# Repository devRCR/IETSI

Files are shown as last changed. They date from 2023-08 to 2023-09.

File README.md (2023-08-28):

# Sistema de llamada para pacientes mediante módulos inalámbricos

Solución tecnológica diseñada para facilitar la comunicación entre el personal médico o de enfermería y los pacientes en entornos de atención médica, como hospitales o clínicas, mediante el uso de módulos de radiofrecuencia con pulsadores que realizan las funciones de "Atender paciente", "Rellamar" y "Finalizar".

## Table of Contents

- [Introducción](#introducción)
- [Características](#características)
- [Requisitos](#requisitos)
- [Instalación](#instalación)
- [Uso](#uso)
- [Contribución](#contribución)
- [Licencia](#licencia)
- [Contacto](#contacto)

## Introducción

Proporciona una introducción concisa de lo que hace tu proyecto y por qué es relevante. Incluye un resumen de las principales características y beneficios.

## Características

Enumera las características clave de tu proyecto. Esto puede ser una lista de funcionalidades, capacidades o aspectos destacados.

- Característica 1
- Característica 2
- ...

## Requisitos

Enumera los requisitos previos que deben estar instalados en el sistema del usuario para que tu proyecto funcione correctamente. Esto podría incluir software, bibliotecas o cualquier otro componente necesario.

## Instalación

Proporciona instrucciones detalladas sobre cómo instalar tu proyecto. Incluye comandos, configuraciones o pasos específicos necesarios para la instalación.

```bash
git clone https://github.com/tu-usuario/tu-proyecto.git
cd tu-proyecto
npm install # o cualquier otro comando de instalación

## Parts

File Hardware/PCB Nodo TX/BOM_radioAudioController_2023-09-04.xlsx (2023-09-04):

ID | Name | Designator | Footprint | Qty | Manufacturer Part | Manufacturer | Supplier | Supplier Part | Unit Price | Subtotal Price
1 | 0.1u | C1,C2,C3,C4,C5,C9 | C0805 | 6 | CC0805JRX7R7BB104 | YAGEO(国巨) | LCSC | C520082 | 0.010 | 0.060
2 | 2.2uF | C6 | C0805 | 1 | CC0805KKX5R9BB225 | YAGEO(国巨) | LCSC | C326581 | 0.028 | 0.028
3 | 1uF | C7 | C0805 | 1 | TCC0805X7R105K250DTS | CCTC | LCSC | C344171 | 0.009 | 0.009
4 | 470pF | C8 | C0805 | 1 | TCC0805X7R471K501FT | CCTC(三环) | LCSC | C376985 | 0.011 | 0.011
5 | 1u | C10 | C0805 | 1 | CC0805ZRY5V8BB105 | YAGEO(国巨) | LCSC | C106837 | 0.010 | 0.010
6 | FTDI Header | H1 | HDR-F-2.54_1X6 | 1 | PZ2.54-1*6-FWZ | ZHOURI(洲日) | LCSC | C5224019 | 0.041 | 0.041
7 | RESET | KEY1 | KEY-SMD_4P-L6.0-W6.0-P3.90-LS10.0 | 1 | K2-6639SP-D4SC-04 | 韩国韩荣 | LCSC | C191626 | 0.043 | 0.043
8 | BT1 | KEY2 | KEY-TH_4P-L6.0-W6.0-P4.50-LS6.5 | 1 | K2-1102DP-E4SW-04 | 韩国韩荣 | LCSC | C136684 | 0.043 | 0.043
9 | BT2 | KEY3 | KEY-TH_4P-L6.0-W6.0-P4.50-LS6.5 | 1 | K2-1102DP-E4SW-04 | 韩国韩荣 | LCSC | C136684 | 0.043 | 0.043
10 | BT3 | KEY4 | KEY-TH_4P-L6.0-W6.0-P4.50-LS6.5 | 1 | K2-1102DP-E4SW-04 | 韩国韩荣 | LCSC | C136684 | 0.043 | 0.043
11 | VBAT | P1 | HDR-TH_2P-P2.54-V-F | 1 | 2.54-1*2PFemale | BOOMELE | LCSC | C49661 | 0.035 | 0.035
12 | 10k | R1 | R0805 | 1 | RC0805FR-7W10KL | YAGEO(国巨) | LCSC | C723404 | 0.004 | 0.004
13 | 100k | R2 | R0805 | 1 | RC0805JR-07100KL | YAGEO(国巨) | LCSC | C100049 | 0.002 | 0.002
14 | MIC5219 | U1 | SOT-23-5_L2.9-W1.6-P0.95-LS2.8-BR | 1 | MIC5219-2.9YM5-TR | MICROCHIP(美国微芯) | LCSC | C625857 | 1.247 | 1.247
15 | ATMEGA328P-AU | U2 | TQFP-32_L7.0-W7.0-P0.80-LS9.0-BL | 1 | ATMEGA328P-AU | MICROCHIP(美国微芯) | LCSC | C14877 | 2.431 | 2.431
16 | RFM69HW | U3 | RFM69W-XXXS2 | 1 | DL-RFM69HC-915M | DreamLNK(骏晔科技) | LCSC | C2844478 | 3.212 | 3.212
17 | 8MHz | X1 | CRYSTAL-SMD_L11.4-W4.8-LS12.7 | 1 | 72008000RW1 | HD(浩都频率) | LCSC | C655077 | 0.078 | 0.078
18 | Batería LiPo 3.7V 1000mAh | B1 |  | 1 |  |  | MTLab |  | 4.865 | 4.865
19 | TP4056 | CH1 |  | 1 |  |  | MTLab |  | 3.244 | 3.244
20 | Cargador de pared |  |  | 1 |  |  | Mdo Libre |  | 4.054 | 4.054
21 | Fabricación PCB |  |  | 1 |  |  | JLPCB |  | 1.901 | 1.901
 |  |  |  |  |  |  |  | TOTAL (USD) | 21.354 | 21.404
 |  |  |  |  |  |  |  | TOTAL (PEN) | 79.010 | 79.195

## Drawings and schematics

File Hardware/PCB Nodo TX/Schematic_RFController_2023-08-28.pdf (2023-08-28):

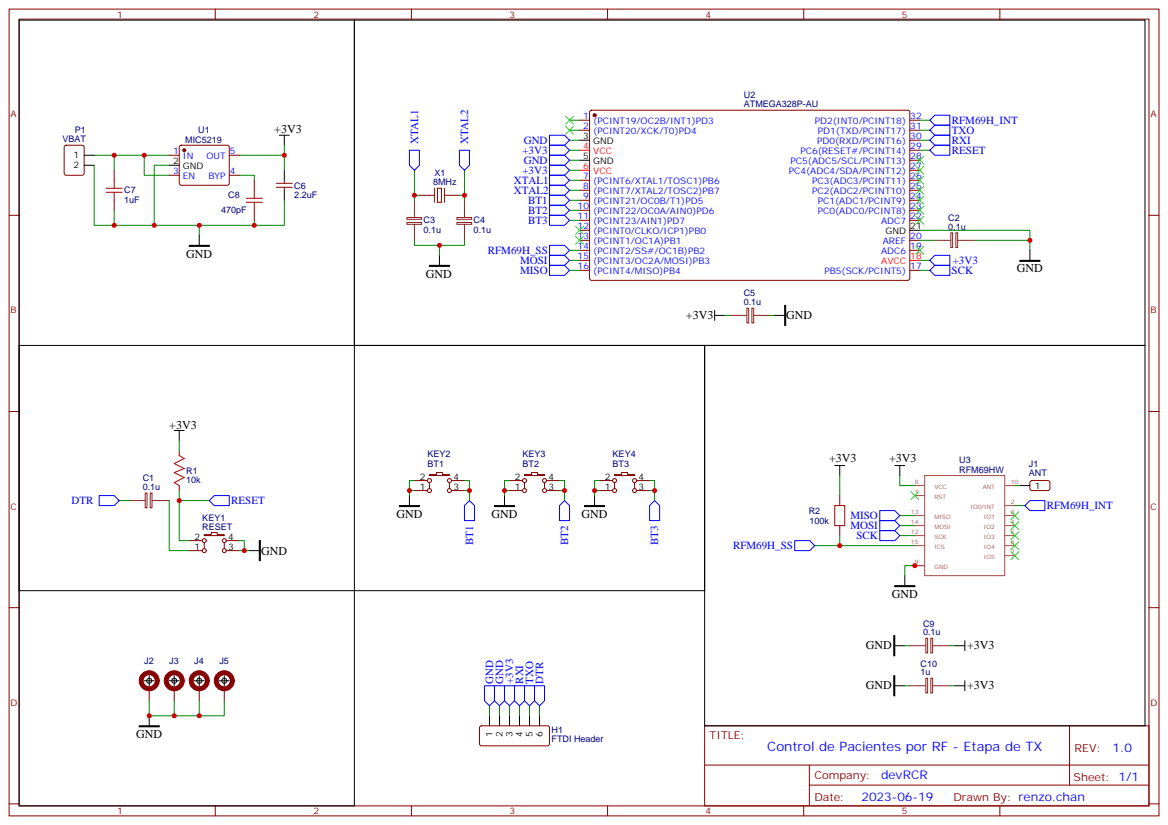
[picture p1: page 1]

Drawn By: renzo.chan

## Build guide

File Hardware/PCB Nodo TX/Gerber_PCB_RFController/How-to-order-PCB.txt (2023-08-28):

How to Order PCB

Please refer to:
https://docs.easyeda.com/en/PCB/Order-PCB

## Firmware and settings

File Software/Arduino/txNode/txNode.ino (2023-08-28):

/***************************************************************
// Mando inalámbrico para sistema de llamado de pacientes
// by Renzo Chan
// ver. 0.2
****************************************************************/
#include <SPI.h>
#include <RH_RF69.h>
#include <RHReliableDatagram.h>

const int pushButton = 12;      // Pulsador conectado al pin 12 de la tarjeta

/************ Radio Setup ***************/
#define RF69_FREQ 915.0         // Frecuencia de 915 MHz
#define MY_ADDRESS   3          // ID del mando (acá podría ir el ID del Usuario Ventanillero)
#define DEST_ADDRESS 1          // ID de la estación base (recepciona las solicitudes de los mandos)

// Configuración de pines del módulo RFM69
#define RFM69_CS    8
#define RFM69_INT   3
#define RFM69_RST   4
#define LED        13

// Instancia del objeto de controlador de radio
RH_RF69 rf69(RFM69_CS, RFM69_INT);

// Clase para gestionar la entrega y recepción de mensajes, utilizando el controlador declarado anteriormente.
RHReliableDatagram rf69_manager(rf69, MY_ADDRESS);

void setup() {
  Serial.begin(115200);
  pinMode(pushButton, INPUT_PULLUP);
  pinMode(LED_BUILTIN, OUTPUT);
  digitalWrite(LED_BUILTIN, LOW);

  pinMode(RFM69_RST, OUTPUT);
  digitalWrite(RFM69_RST, LOW);

  // reset manual
  digitalWrite(RFM69_RST, HIGH);
  delay(10);
  digitalWrite(RFM69_RST, LOW);
  delay(10);

  if (!rf69_manager.init()) {
    Serial.println("RFM69 radio init failed");
    while (1);
  }
  Serial.println("RFM69 radio init OK!");
  if (!rf69.setFrequency(RF69_FREQ)) {
    Serial.println("setFrequency failed");
  }

  rf69.setTxPower(20, true); 

  // La clave de cifrado debe ser la misma que la del cliente.
  uint8_t key[] = { 0x01, 0x02, 0x03, 0x04, 0x05, 0x06, 0x07, 0x08,
                    0x01, 0x02, 0x03, 0x04, 0x05, 0x06, 0x07, 0x08 };
  rf69.setEncryptionKey(key);

  Serial.print("RFM69 radio @");  Serial.print((int)RF69_FREQ);  Serial.println(" MHz");
}

// No colocar esto en el void loop, ni void setup
uint8_t buf[RH_RF69_MAX_MESSAGE_LEN];
uint8_t data[] = "  OK";

void loop() {
  bool stateButton = digitalRead(pushButton);

  if (stateButton == LOW) {
    char radiopacket[20] = "*31A";
    Serial.print("Enviando "); Serial.println(radiopacket);

    // Envio del mensaje al destino
    if (rf69_manager.sendtoWait((uint8_t *)radiopacket, strlen(radiopacket), DEST_ADDRESS)) {
      // Esperamos por la respuesta del server
      uint8_t len = sizeof(buf);
      uint8_t from;
      if (rf69_manager.recvfromAckTimeout(buf, &len, 2000, &from)) {
        buf[len] = 0; // poner a 0 el string restante

        Serial.print("Obteniendo respuesta de #"); Serial.print(from);
        Serial.print(" [RSSI :");
        Serial.print(rf69.lastRssi());
        Serial.print("] : ");
        Serial.println((char*)buf);
        Blink(LED, 40, 3); // LED parpadea 3 veces, 40 ms entre parpadeo
      } else {
        Serial.println("No hay respuesta, el servidor está operativo?");
      }
    } else {
      Serial.println("Envio fallido");
    }
  }
}

void Blink(byte pin, byte delay_ms, byte loops) {
  while (loops--) {
    digitalWrite(pin, HIGH);
    delay(delay_ms);
    digitalWrite(pin, LOW);
    delay(delay_ms);
  }
}

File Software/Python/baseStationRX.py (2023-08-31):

import serial, time, json, requests, rel, websocket

# Configura el puerto serial
baseStation = serial.Serial('COM6', 115200)  # Cambia 'COM1' al nombre de tu puerto serial

url = 'https://appsqa.essalud.gob.pe/sagw/gestatenpuls/atender-cola'
headers = {'Content-type': 'application/json'}

try:
    while True:
        # Lee una línea desde el puerto serial
        data = baseStation.readline()
        
        # Decodifica los bytes a una cadena (ajusta el formato según lo que envía tu dispositivo)
        decoded_data = data.decode('utf-8').strip()
        
        # Imprime y realiza funciones de acuerto al mando recibido        
        if(decoded_data=='*21A'):
            print("Ventanilla 1")
            # acá se debe agregar las otras rutinas para que haga el post
            data = '{"guiidOperador":"fH09AI01ul-332469d2-0c30-4622-9f39-68c5442c0f7e-Gi23hz23RK-My54lO54Rz","ventanilla": "2","codOficina": "11"}'
            response = requests.post(url, headers=headers, auth=('PwtZZTsCA8oMvuS54DgktZ6RbsOeggXJ', 'glzzsDFKwKk5WDy23RdIkaIkb31nS8kd'), data=data)
            print(response.status_code)
            print(response.text)
            # líneas abajo agregar rutina para el websocket y STOMP Protocol
            
        elif (decoded_data=='*31A'):
            print("Ventanilla 2")
            # acá se debe agregar las otras rutinas para que haga el post
            data = '{"guiidOperador":"iU177A02EP-eb062dc8-0b44-4b21-8a57-b9a0df714af7-6L230u15LN-vn51AZ017K","ventanilla": "2","codOficina": "11"}'
            response = requests.post(url, headers=headers, auth=('PwtZZTsCA8oMvuS54DgktZ6RbsOeggXJ', 'glzzsDFKwKk5WDy23RdIkaIkb31nS8kd'), data=data)
            print(response.status_code)
            print(response.text)
            # líneas abajo agregar rutina para el websocket y STOMP Protocol
        else:
            None

except KeyboardInterrupt:
    # Maneja una interrupción de teclado (Ctrl+C) para salir del bucle
    pass

finally:
    # Cierra el puerto serial al finalizar
    baseStation.close()

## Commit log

2023-08-28 sincronizando archivos
    [Drill_PTH_Through.DRL, Drill_PTH_Through_Via.DRL, Gerber_BoardOutlineLayer.GKO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]
2023-09-04 BOM TX node added
    [BOM_radioAudioController_2023-09-04.xlsx]
2023-09-04 gerber files updated
    [Drill_PTH_Through.DRL, Drill_PTH_Through_Via.DRL, Gerber_BoardOutlineLayer.GKO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]
